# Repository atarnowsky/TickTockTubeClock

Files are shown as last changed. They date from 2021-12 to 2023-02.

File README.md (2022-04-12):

# TickTockTubeClock
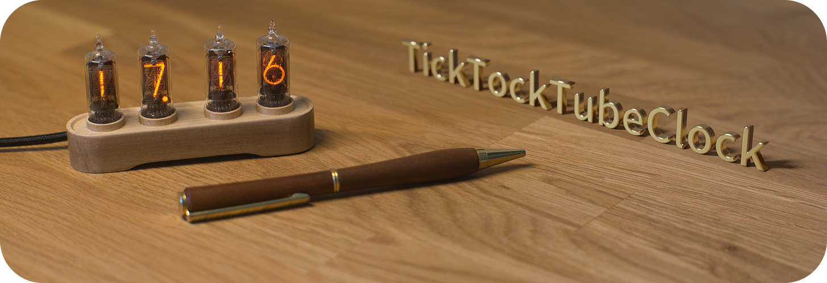
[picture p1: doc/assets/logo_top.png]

The TickTockTubeClock is an open source, open hardware Nixie-Clock with pleasing aesthetics and rich functionality in mind. It combines old nixie tubes from the late sixties with modern miniaturized electronics, 3D printing and pretty advanced wood milling.  

## Background & Introduction
Back in 2020 I gained more and more interest in CNC machining as well as electronic engineering. Searching for a project to overcome lockdown during the pandemic, I stumbled upon an old, defective electrical calculator made by Canon in the late sixties (a Monroe 630, to be more precise - similar to [this one](https://www.oldcalculatormuseum.com/monroe620.html)). Luckily, all 14 Nixie tubes were in good shape, so I decided to make some clocks out of them.

There are many different designs [out there](http://www.electricstuff.co.uk/nixiegallery.html). However, I felt most of them being a little bit too clumsy for the very small [CD81 Tubes from Hitachi](https://www.swissnixie.com/tubes/CD81/), that have been salvaged from the calculator. With the digits only being about 13 mm in height, I decided to design a housing that aesthetically complements these tiny tubes before actually thinking about how to get this thing to work electrically (not to mention to manufacture the housing). There just *had* to be a way to shrink down the electronics...

## Features
* Probably one of the smallest housings possible for a nixie tube that can be either *milled from wood* or *3D printed* using FDM or SLA printers
* Stacked two-PCB construction allows for easy adaption to other nixie tubes with same form factor
* Completely powered by a 5V USB-C connector
* Supercap based backup battery allowing to compensate power losses up to 36 hours
* Color-matched base light
* Sound output and ambient light sensor for automatic dimming
* Easy to program, extensible software interface
* Default firmware ships with:
  * Intuitive 3-button interface
  * Dimming tube and LED brightness (separately)
  * Adjustable ticking sounds
  * 4 different types of cross-fade effects (e.g. fade to black, crossfade)
  * 4 different types of ambient effects (e.g. sporadic flickering of tubes, misfiring effects)
  * Automatic night time dimming based on ambient light
  * Configurable off-time to save power and prolong tube life
  * Readout of temperature sensor of RTC
  * Anti cathode poisoning mode

## Gallery
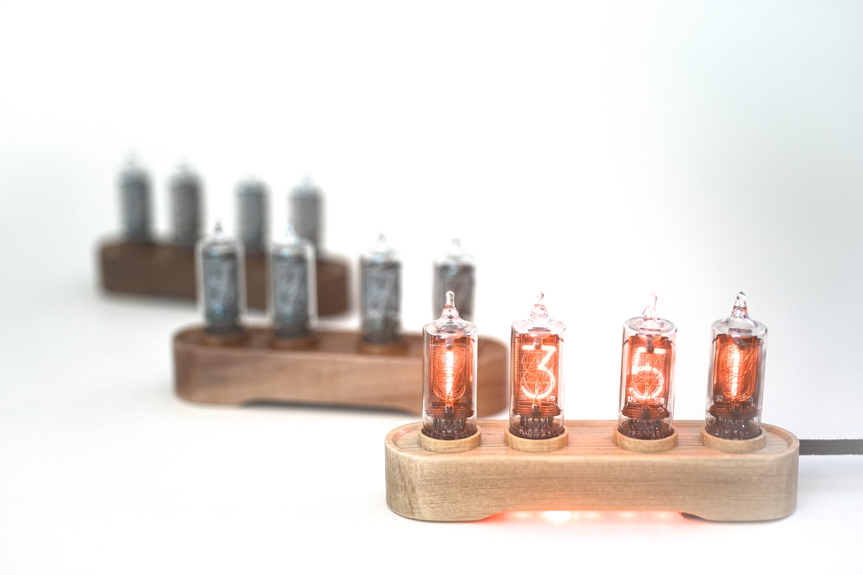
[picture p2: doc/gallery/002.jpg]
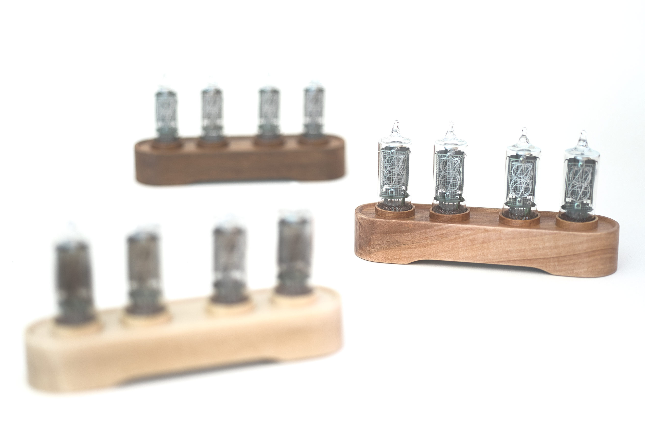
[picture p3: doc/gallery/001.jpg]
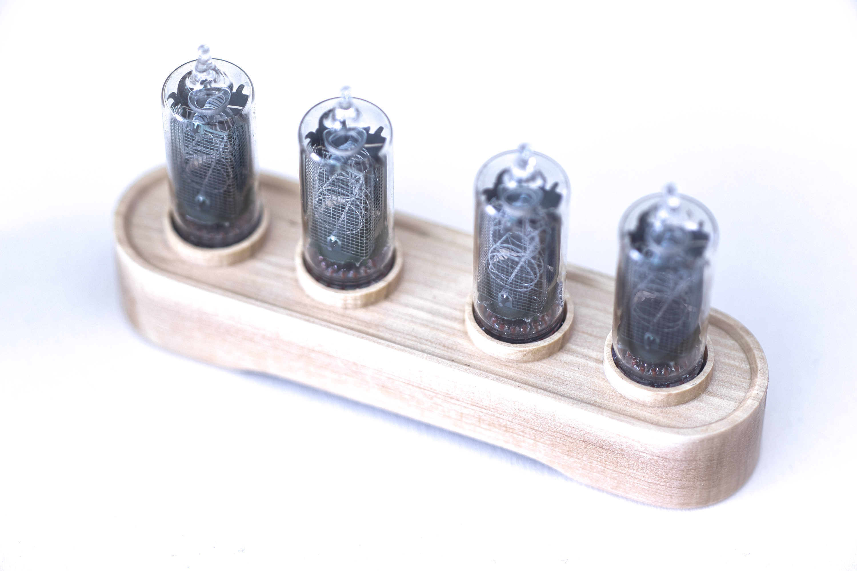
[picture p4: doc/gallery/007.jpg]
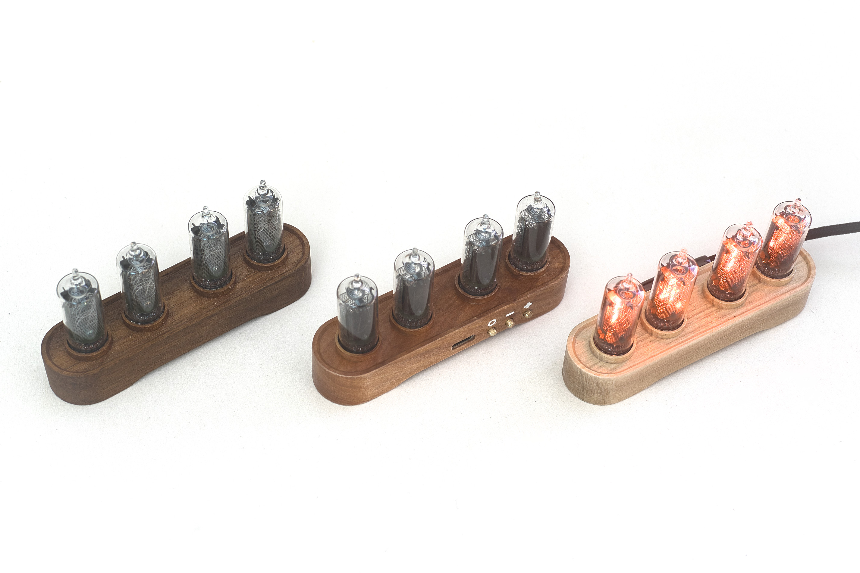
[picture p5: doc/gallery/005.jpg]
|||||
|:---:|:---:|:---:|:---:|
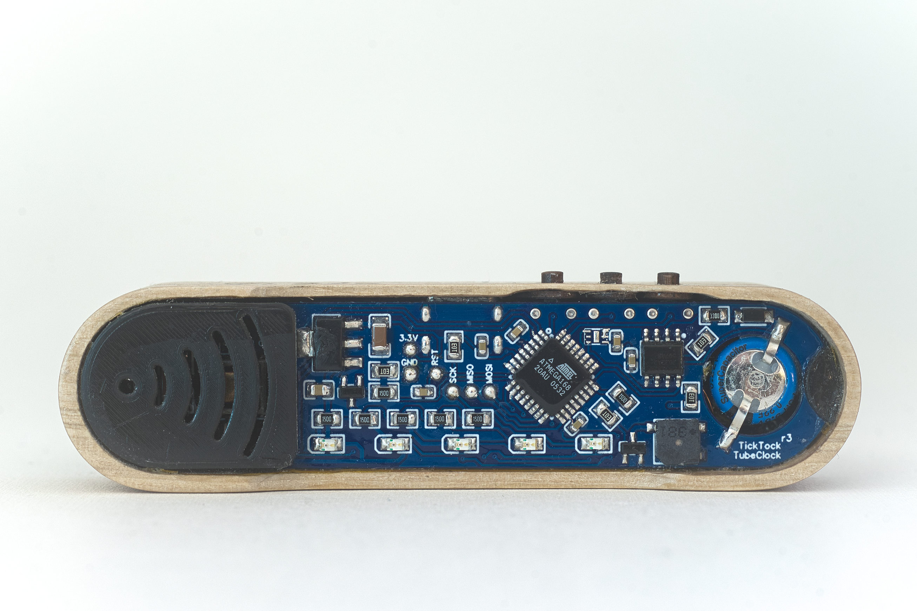
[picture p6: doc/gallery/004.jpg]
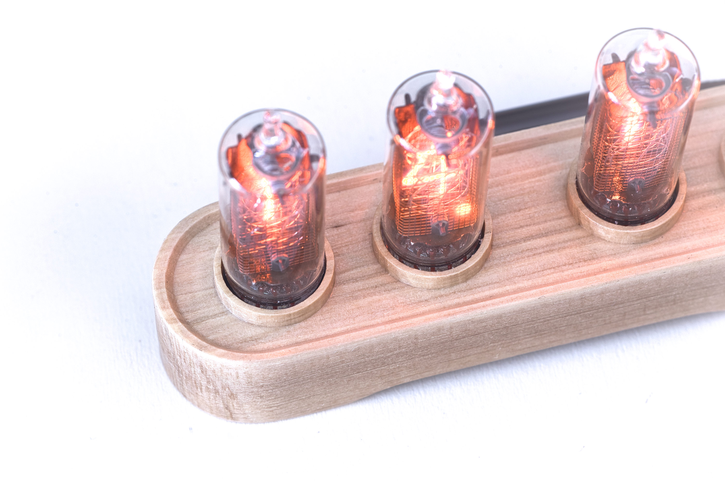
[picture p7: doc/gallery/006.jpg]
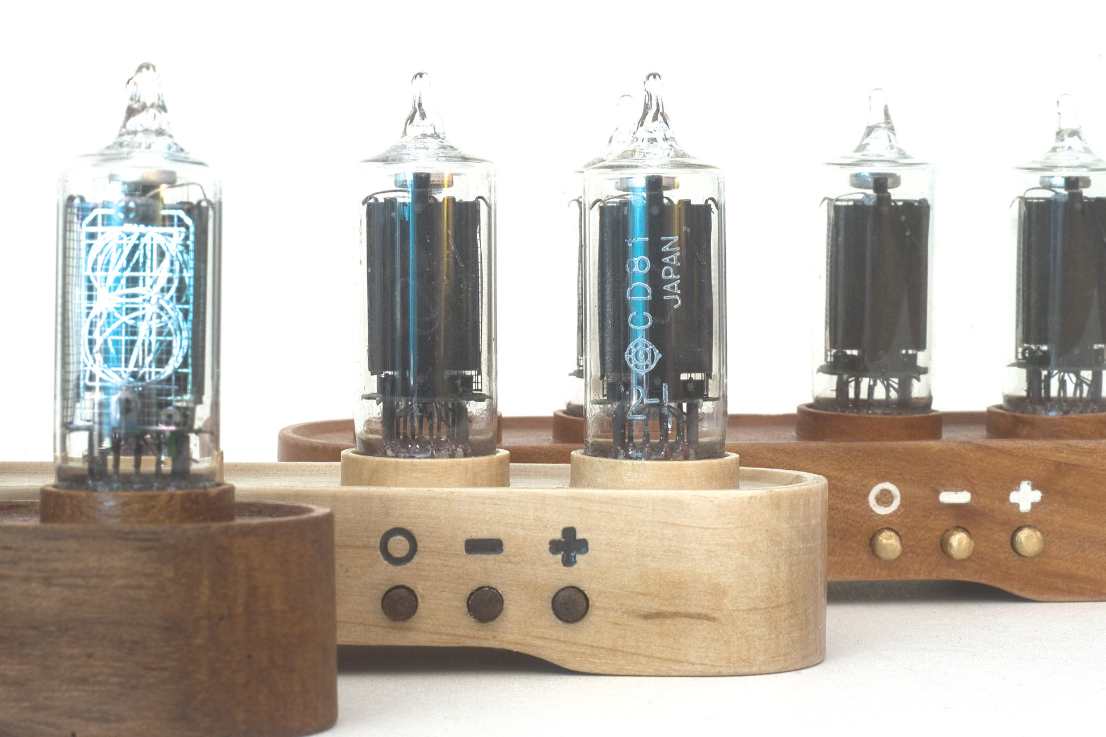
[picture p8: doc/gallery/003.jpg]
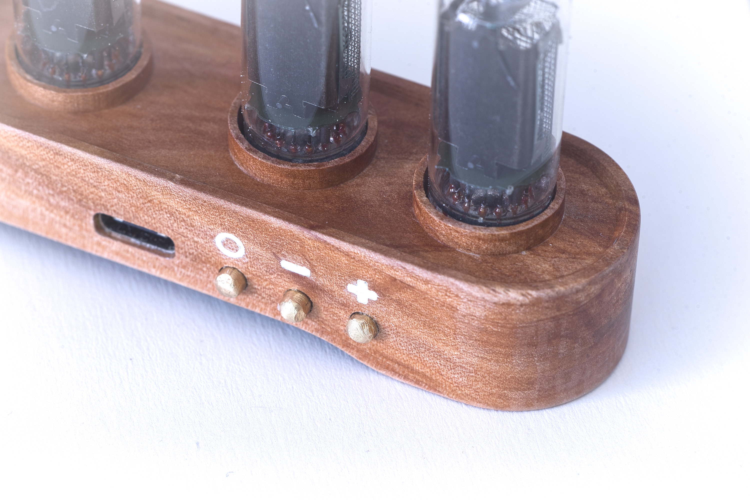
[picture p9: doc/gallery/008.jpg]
|||||

# Technical Data & General Concept
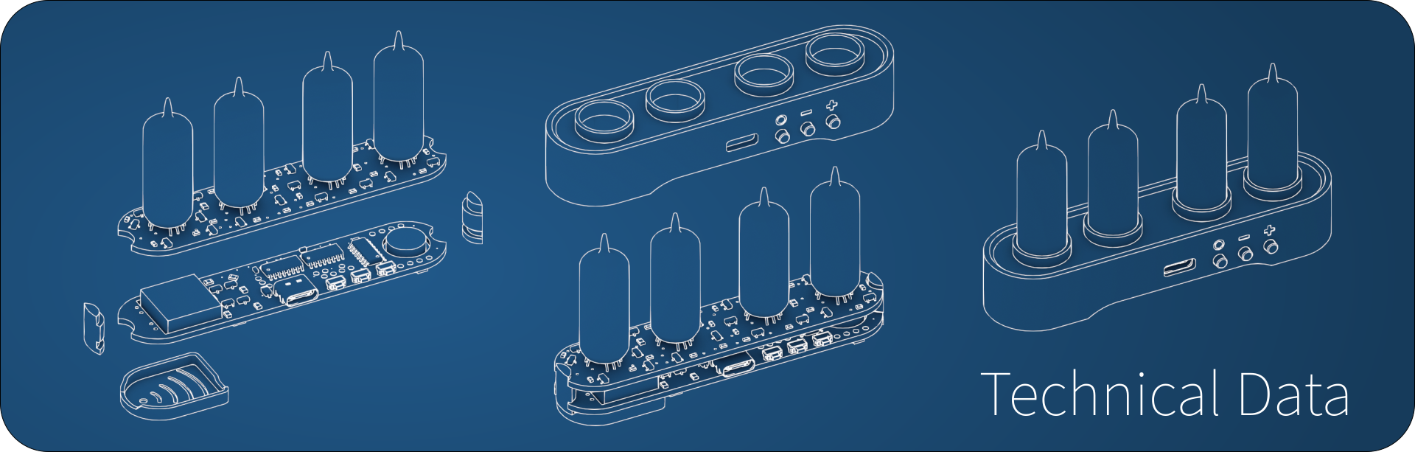
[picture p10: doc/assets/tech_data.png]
Technical Data

The clock consist of multiple parts to achieve the small form factor:
* **Upper module:** The upper PCB mounts four nixie tubes as well as the switching electronics that allows to select the digit to be visible by means of a 5V logic signal. Current limiting is done on this module, making it relatively easy to re-design this PCB for different kinds of nixie tubes without needing to change the lower module.
* **Lower module:** The lower PCB hosts the microcontroller as well as some shift registers that allow to control individual digits. It also contains two high-side switches allowing to mux between two pairs of tubes. This not only reduces the complexity of the switching electronics, but also allows to dim the tubes by using pulse width modulation. Additionally, this board includes two cutouts for mounting the DC/DC converter and a 0.2 F supercapacitor without sacrificing the overall height of the module.
* **Spacers and touch protection:** These 3D printed parts seperate upper and lower module from each other to prevent accidential contact between electrical parts. This space is also needed to route a total of 25 insulated copper wires between both PCBs, transmitting logic as well as high voltage signals. The touch protection contains several holes to allow for some ventilation and prevents accidential contact with the exposed high voltage part of the electronics.
* **Case:** The case can either be made from hardwood or by 3D printing. In either case, the machining tools need to be quite precise since the material thickness ranges from only 0.75 mm to 2.0 mm.

<br />

| Mechnical specs. | | Electrical specs. | |
| - | -: | - | -: |
| Dimensions (width × depth × height) | 9.5 × 2.45 × 5.0 cm | Supply voltage | 5V |
| Weight | approx. 35 g| maximum power consumption | 2.5 W |
| electrical components | 114 | Accuracy | ±2.6 minutes/year |

<br /><br />

# Making your own & Prerequisites

Making the TickTockTubeClock is quite a time consuming endeavor and you will need some mechanical equipment as well as good soldering skills.

## Mechanical equipment
* **3D Printer:**
Either a FDM printer with a rather fine (0.2 mm) nozzle or a SLA printer is fine. The printer is mainly needed for some internal spacers as well as a cover for the high voltage electronics.
  * Theoretically, the whole case can be 3D printed. The result, however, won't be as pleasing as a milled case.
  * When ordered in bulk, using online services such as Shapeways or JLCPCB might be a viable option. <br /><br />

* **CNC Mill:** The mill has to be quite precise but does not neet to be particularly large.
  * It is definitively possible to use a cheap 3018 style CNC mill (I actually did all parts on a slightly modified 3018!). However, you probably need to use very slow feeds, so milling the case out of hard wood will take *many* hours.
  * The 3D geometry to be milled is quite complex, so you will need a powerfull CAM tool for generating tool paths. I used Fusion 360 for CAD as well for CAM.<br /><br />

* **Milling bits:**
  * 3 to 6 mm flat end mill (two flute, for wood) with at least 22 mm cutting edge length.
  * 2 mm flat end mill (two flute, for wood) for fine details.
  * 0.5 - 1 mm end mill for USB port and button cutouts on side.
  * V carve routing bit for details on side.

## Electronics
* **Components:** Please have a look at the Bill of Materials. (As soon as I uploaded it...)
* **DC/DC converter**: This is a tricky one, since we need a DC/DC converter with a large voltage ratio (5V -> 170V). I finally found a suitably small one on Aliexpress: [DKYB DC 5V-9V to 170V](https://www.aliexpress.com/item/32990383358.html).
* **Additional isolation:** To be on the save side when handling a device with high voltages, I heavily recommend to apply some conformal coating on the assembled PCB. I used a [acrylic based one](https://cramolin-shop.de/cramolin-plastik-400-ml-spraydose-1201611) with great results.
* **SMD soldering:** All components can be soldered by hand (mostly 0805, some 0603 footprints). There are, however, some delicate parts in the BoM that need a steady hand and good eyes (or a microscope). Especially the USON6 package of the [OPT3001](https://www.ti.com/lit/ds/symlink/opt3001.pdf?ts=1649591341957&ref_url=https%253A%252F%252Fwww.google.com%252F) ambient light sensor is quite challenging.

## Software
* The clock uses an ATMega 168 processor from microchip. The programming/flashing is done via PlatformIO.
* There just was not enough space for a USB to serial chip on the PCB, so a ISP programmer is needed for flashing the device.

<br />

**More information and some tutorials are coming soon...**

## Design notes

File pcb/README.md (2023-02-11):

# Bill of Materials

There was simply not enough space on the PCB for proper designators. Instead, please consult the color-code besides the _No._ column and the respective images of the PCB.

Number column: 

**A** = Lower PCB / Lower side, **B** = Lower PCB / Upper side

**C** = Upper PCB / Lower side, **D** = Upper PCB / Upper side

### Integrated Circuits, Diodes & Mosfets
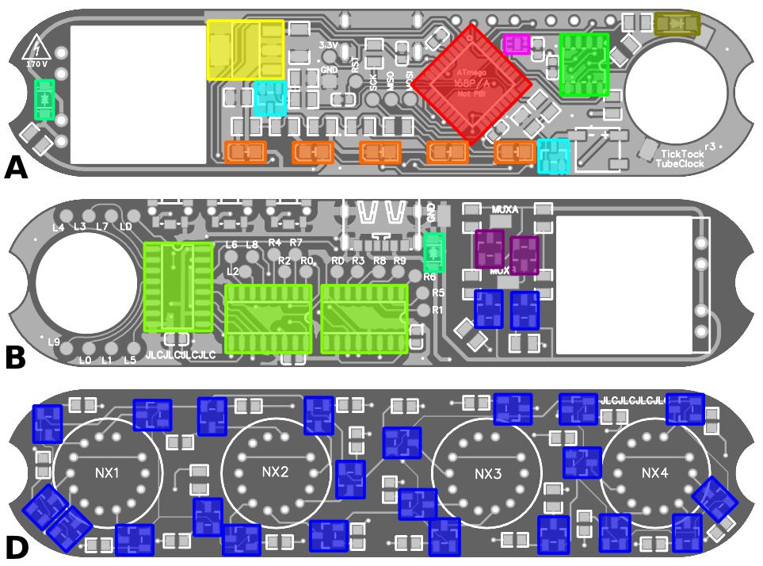
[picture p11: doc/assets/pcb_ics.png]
Components: ICs


| No. | Qty | Package | Manufacturer | Part number | Description | Alternatives |
|---|-----|---|---|---|---|---|
| #ff0000 A1 | 1 | QFP32 | Microchip | ATMEGA168-20AU | 8bit microcontroller | P variant is also okay, but **not -PB!**. ATMEGA328 if more memory is needed. |
| #ffff00 A2 | 1 | SOT-223 | Texas Instruments | LM3940IMP-3.3  | Voltage regulator 3.3V | Any pin-compatible LDO proably will do. However, stabilizing capacitors need adjusment depending on data-sheet. |
| #00ff00 A3 | 1 | SOIC-8  | Maxim Integrated  | DS3232MZ/V+ | Real time clock with integrated oscillator | DS3231MZ+, DS3231M (both untested) needs compatible footprint + internal oscillator | 
| #ff00ff A4 | 1 | USON-6  | Texas Instruments | OPT3001DNPR | Ambient light sensor | OPT3002 should work as well |
| #00ffff A5 | 2 | SOT-23  | Diodes Inc. | DMN2041L-7 | n-channel MOSFET | IRLML2502 or similar, needs a 3.3V logic level compatible Gathe-threshold voltage (< 1.5V) |
| #ff6600 A6 | 5 | 0805 | Würth Elektronik  | 150080AS75000  | LED Amber/Orange 2V/20mA | Any similar LED will do. Using a color matching the nixies closely recommended. |
| #808000 A7 | 1 | SOD-123 | Nexperia | BAT54GWX | Schottky diode | Maybe RB168MM-40. **See description below** |
| #00ff80 AB8  | 2 | SOD-123 | Eaton | STS321050B331  | TVS diode | Used for securing the USB port as well as the 5V input rail of the DC/DC convertor (in case of voltage spikes when malfunctioning). |
| #80ff00 B9 | 3 | SOIC-16 | Texas Instruments | SN74HC595 | 8bit shift register | |
| #800080 B10  | 2 | SOT-23  | Various | MMBTA92 | High voltage transistor, p-channel | |
| #0000ff BC11 | 24  | SOT-23  | Various | MMBTA42 | High voltage transistor, n-channel | |

**Note on schottky diode (A7)**

This diode is used for charging the supercapacitor and needs special attention in order to maximize battery backup time:
Ideally, a diode is chosen with an extremely low forward voltage (so the maximum charging voltage of the supercap is near 3.3V) as well as a very low reverse current (preventing discharge over time).
After some quite extensive search, the BAT54GWX seems to be a reasonable choice. For a maximum voltage of 3.3V, the reverse current should be as low as 0.5 µA while the voltage drop should stay below 240 mV.
The current consumption of the RTC in backup mode typically is about 1.8 µA, so further reducing the reverse current of the diode should significantly prolong battery backup time.

Using the BAT54GWX, about 30-36 hours of backup time can be expected. <br />
**If you find a better diode, please tell me!**

### Capacitors & Resistors

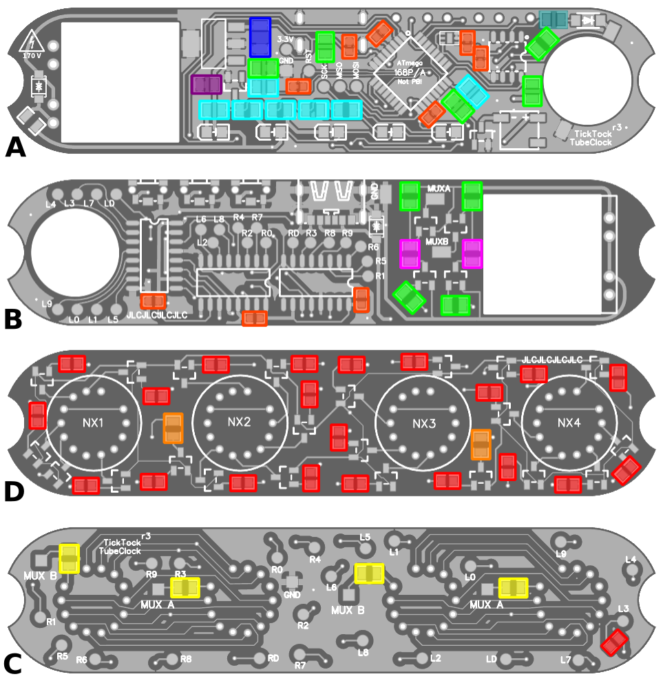
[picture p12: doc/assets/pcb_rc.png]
Components: Resistors and Capacitors


| No. | Qty | Package | Description | Annotations |
|---|-----|---|---|---|
| #ff4000 AB12  |  9  | 0603 | **C:** 100nF/50V X7R Generic decoupling capacitor | 16V rating should be also sufficient. |
| #800080 A13 |  1  | 0805 | **C:** 470nF/25V X7R capacitor | Needs to be matched with LDO specifications. |
| #0000FF A14 |  1  | 1206 | **C:** 33µF/16V X5R capacitor | Needs to be matched with LDO specifications. |
| #00FF00 AB15  |  9  | 0805 | **R:** 10kΩ resistor 1/4W | Can be replaced with something in the 4-16kΩ range. |
| #00FFFF A16 |  7  | 0805 | **R:** 150Ω resistor 1/4W | |
| #008080 A17 |  1  | 0805 | **R:** 150Ω resistor 1/4W | For charging the supercap. Reduce value for faster charging, but shorter supercap life. |
| #FF00FF B18 |  2  | 0805 | **R:** 1MΩ resistor 1/8W | Mega-Ohms! You really do not want milli Ohms here ;-) |
| #FF8000 D19 |  2  | 0805 | **R:** 2.4kΩ resistor 2/5W | Controls relative brightness of decimal-dots. Might be varied to match better. |
| #FF0000 BC20  | 22  | 0603 | **R:** 10kΩ resistor 1/4W | |
| #FFFF00 C21 |  4  | 0805 | **R:** 16kΩ resistor 2/5W | In theory, these should be ~2W rated. However, due to multiplexing and PWM effective current is greatly reduced. |

### Other Components

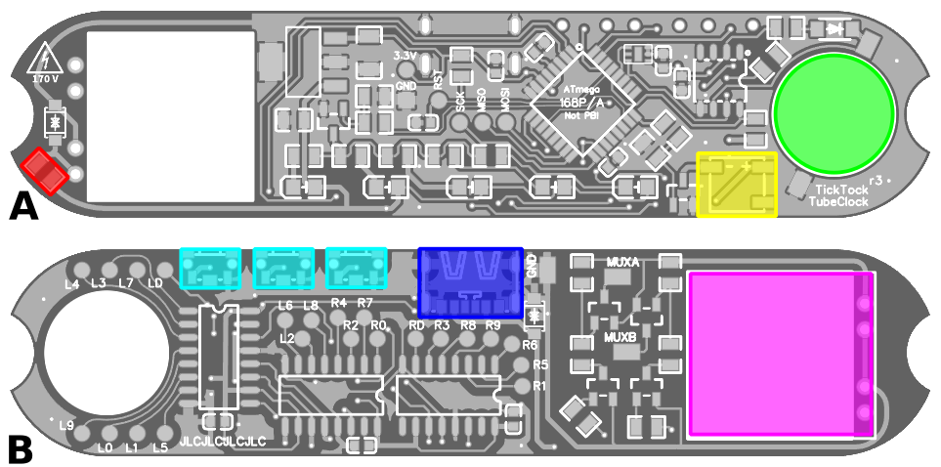
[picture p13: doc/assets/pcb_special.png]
Components: Special


| No. | Qty | Package | Manufacturer | Part number | Description | Alternatives |
|---|-----|---|---|---|---|---|
| #ff0000 A22  | 1 | 0603 | Bourns | SF-0603HI075F-2 | Fuse 750mA High Inrush Withstand | 500mA might be sufficient as well. Needs long-time testing. 0Ω jumper if you feel adventurous. |
| #ffff00 A23  | 1 | special | CUI Devices | CMT-5023S-SMT-TR | Magnetic Buzzer | KELIKING KLJ-5018 is cheaper but sounds worse. |
| #00ff00 A24  | 1 | special | Various | | Super Capacitor >3.3V | **See description below** |
| #00ffff B25  | 3 | special | Diptronics | TCD-C2KQR | Right angle tactile switch | |
| #0000ff B26  | 1 | special | Korean Hroparts Elec | TYPE-C-31-M-16 | USB-C Power-only jack | |
| #ff00ff B26  | 1 | THT | DKYB | [Link](https://www.aliexpress.com/item/32990383358.html) | 5V to 170V DC/DC converter | If you are able to design a on-board circuit, please contact me! |

**Note on supercapacitor (A24)**

Any supercapacitor with (at least) 3.3V will be fine. Use a higher voltage one and/or larger values for A17 to prolong its life expectancy.
The PCB originally has been designed to hold a *5V/0.1F Eaton Gold Cap* (10mm diameter, 4mm height), but slightly larger ones should also fit (max. diameter 12mm, max. height about 6mm).
With 0.1F capacity, one can expect about 30h of timekeeping if USB power is lost.
Choosing a hibrid capacitor, like the Vishay MAL219691203E3 (should barely fit), with 15F/4.2V a total of 60 days should be possible. However, I am unsure regarding the life expectancy of the cell and its self discharging properties.

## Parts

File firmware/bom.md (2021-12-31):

# Bill of materials

All costs are approximate (in €) basedon Digikey prices as of 2022. (Including bulk discount, values are for reference only.)

## Upper PCB

| Comment | Description | Designator | Footprint | Amount | Price (sum.) | Link | Remarks |
| --- | --- | --- | --- | --- | --- | ---- | --- |
| Old stock | Hitachi CD81 | NX1, NX2, NX3, NX4 | Custom | 4 |  n/a | n/a | Might be salvaged from old Canon calculators. (Do not get fooled by Ebay prices!) |
| ESR10EZPJ163 | 16k Resistor, 0.4 W | R1, R32, R57, R58 | 0805 | 4 | 0.12 € | [Digikey](https://www.digikey.de/de/products/detail/rohm-semiconductor/ESR10EZPJ163/4051315) | Be careful wrt. voltage ratings. |
| RCS08052K49FKEA | 2.4k Resistor, 0.4 W | R55, R56 | 0805 | 2 | 0.39 € | [Digikey](https://www.digikey.de/de/products/detail/vishay-dale/RCS08052K49FKEA/5869310) | Be careful wrt. voltage ratings. |
| ESR03EZPJ103 | 10k Resistor, 0.125 W | R33-R54 | 0603 | 22 | 0.62 € | [Digikey](https://www.digikey.de/de/products/detail/rohm-semiconductor/ESR03EZPJ103/1762722) |  |
| MMBTA42,215 | NPN HV-Transistor | Q1-Q11, Q16-Q26 | SOT-23-3 | 22 | 2.18 € | [Digikey](https://www.digikey.de/de/products/detail/nexperia-usa-inc/MMBTA42-215/1156601) | |

## Lower PCB

| Comment | Description | Designator | Footprint | Amount | Price (sum.) | Link | Remarks |
| --- | --- | --- | --- | --- | --- | ---- | --- |
| CMT-5023S-SMT-TR | Buzzer 5x5mm | BUZZER | Custom | 1 |  2.55 € | [Digikey](https://www.digikey.de/de/products/detail/cui-devices/CMT-5023S-SMT-TR/6012414) | Cheaper alternative from [LCSC](https://lcsc.com/product-detail/Buzzers_KELIKING-KLJ-5018_C201045.html) |
| OPT3001DNPR | Ambient light sensor | U3 | 6-UDFN | 1 | 2,77 € | [Digikey](https://www.digikey.de/de/products/detail/texas-instruments/OPT3001DNPR/5039362) | Hard to solder by hand | 
| SMMBTA92LT1G | PNP HV-Transistor | Q12, Q14 | SOT-23-3 | 2 | 0.58 € | [Digikey](https://www.digikey.de/de/products/detail/onsemi/SMMBTA92LT1G/3062778) ||
| MMBTA42,215 | NPN HV-Transistor | Q13, Q28 | SOT-23-3 | 2 | 0.20 € | [Digikey](https://www.digikey.de/de/products/detail/nexperia-usa-inc/MMBTA42-215/1156601) | |
| MFU0805FF00500P100 | Fuse 500mA | F1 | 0805 | 1 | 0,49 € | [Digikey](https://www.digikey.de/de/products/detail/vishay-beyschlag-draloric-bc-components/MFU0805FF00500P100/1206486) | |
| STS321050B331 | TVS Diode 5.5V | ? | SOD-323 | 1 | 0.25 € | [Digikey](https://www.digikey.de/de/products/detail/eaton-electronics-division/STS321050B331/13280450) ||
| SN74HC595DR | Shift register 8bit | U7, U8, U9 | SOIC-16 | 3 | 1.34 € | [Digikey](https://www.digikey.de/de/products/detail/texas-instruments/SN74HC595DR/562919) ||
| LM3940IMPX-3.3/NOPB | 3.3V Linear regulator | U4 | SOT-223-4 | 1 | 1.46 € | [Digikey](https://www.digikey.de/de/products/detail/texas-instruments/LM3940IMPX-3-3-NOPB/367097) ||
| C3216X5R1C336M160AB | Capacitor 33µF | C3 | 1206 | 1 | 0.70 € | [Digikey](https://www.digikey.de/de/products/detail/tdk-corporation/C3216X5R1C336M160AB/2443480) || 
| CL21B474KAFNNNE | Capacitor 470nF | C4 | 0805 | 1 | 0.03 € | [Digikey](https://www.digikey.de/de/products/detail/samsung-electro-mechanics/CL21B474KAFNNNE/3886732) ||
| CL10B104KB8WPNC | Capacitor 100nF | C2, C5-C10 | 0603 | 7 | 0.13 € | [Digikey](https://www.digikey.de/de/products/detail/samsung-electro-mechanics/CL10B104KB8WPNC/5961338) ||
| ERJ-P06J151V | Resistor 150 | R2, R9-R14, R24 | 0805 | 8 | 0.29 € | [Digikey](https://www.digikey.de/de/products/detail/panasonic-electronic-components/ERJ-P06J151V/525217) ||
| RMCF0805JG10K0 | 10k Resistor, 0.125 W | R3, R5, R8, R25, R26, R28, R29 | 0805 | 7 | 0.09 € | [Digikey](https://www.digikey.de/de/products/detail/stackpole-electronics-inc/RMCF0805JG10K0/1757769) |  | 
| RMCF0805JT1M00 | 1M Resistor, 0.125 W | R27, R30 | 0805 | 2 | 0.02 € | [Digikey](https://www.digikey.de/de/products/detail/stackpole-electronics-inc/RMCF0805JT1M00/1757878) || 
| UJC-HP-3-SMT-TR | USB-C Terminal | USB1 | | 1 | 0.88 € | [Digikey](https://www.digikey.de/de/products/detail/cui-devices/UJC-HP-3-SMT-TR/12173295) || 
| DS3232MZ+TRL | RTC integrated Osc. | U2 | SOIC-8 | 1 | 7,91 € | [Digikey](https://www.digikey.de/de/products/detail/analog-devices-inc-maxim-integrated/DS3232MZ-TRL/3087654) || 
| RB168MM-30TR | Diode (Schottky) | D1 | SOD-123 | 1 | 0.31 € | [Digikey](https://www.digikey.de/de/products/detail/rohm-semiconductor/RB168MM-30TR/10670912) | Use low drop out AND very low leakage current diode (standard or schottky) to prolong buffer time | 
| DMN2041L-7 | MOSFET | Q15, Q27 | SOT-23-3 | 2 | 0.36 € | [Digikey](https://www.digikey.de/de/products/detail/diodes-incorporated/DMN2041L-7/2182568) | Use any FET with low Vgs(th), 3.3V compatible |

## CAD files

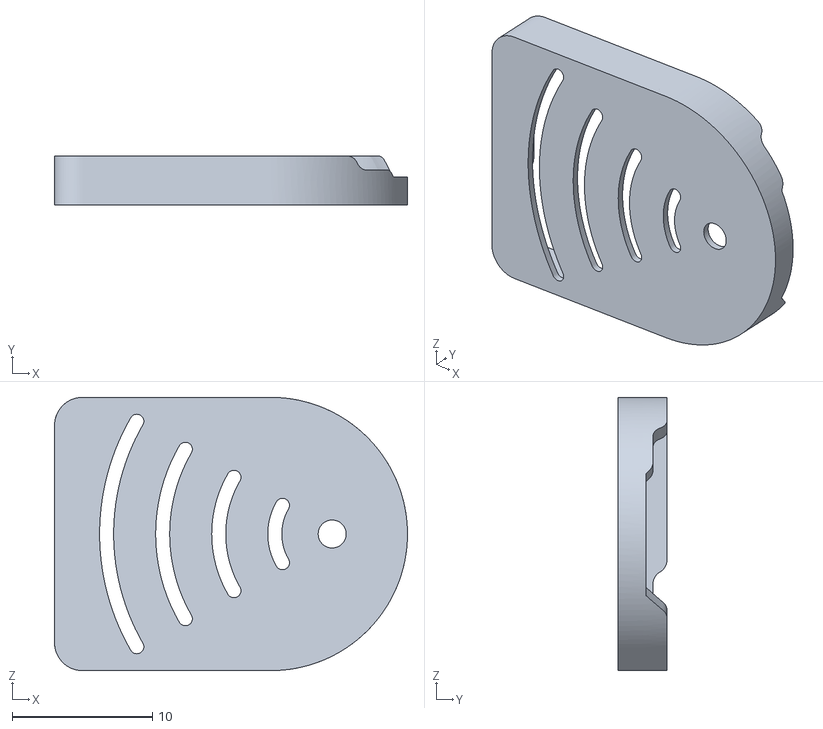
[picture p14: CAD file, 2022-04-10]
cad/stl/touch_guard.stl
25.2 x 3.50 x 19.5

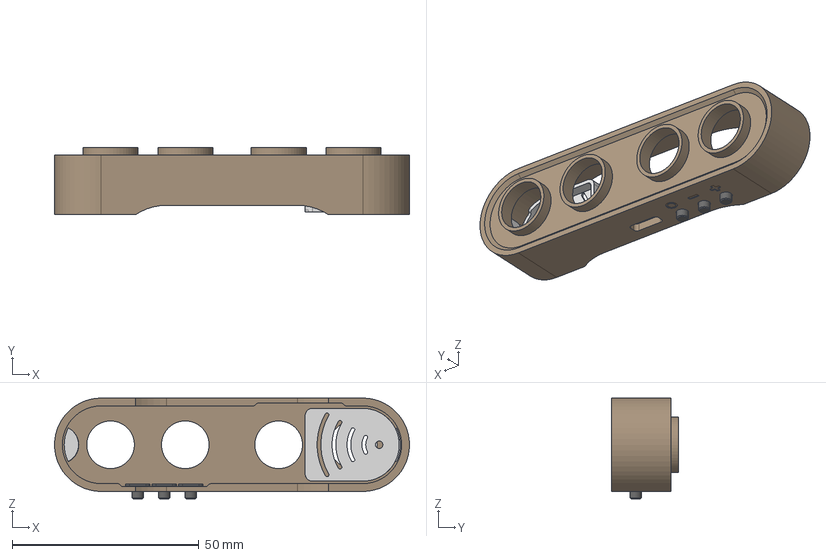
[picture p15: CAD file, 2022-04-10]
cad/tttc.step
95.0 x 18.0 x 27.0 mm
Case
SLA Printed inner spacer

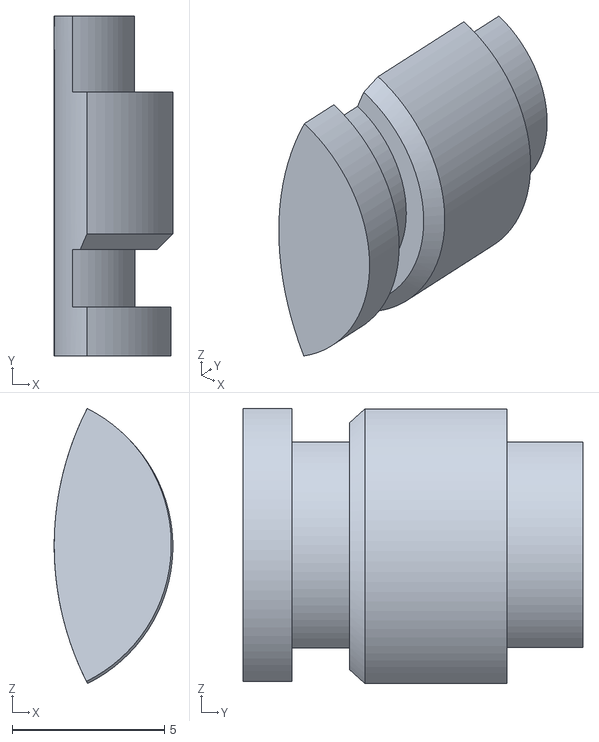
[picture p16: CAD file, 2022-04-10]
cad/stl/spacer.stl
3.89 x 11.1 x 9.03

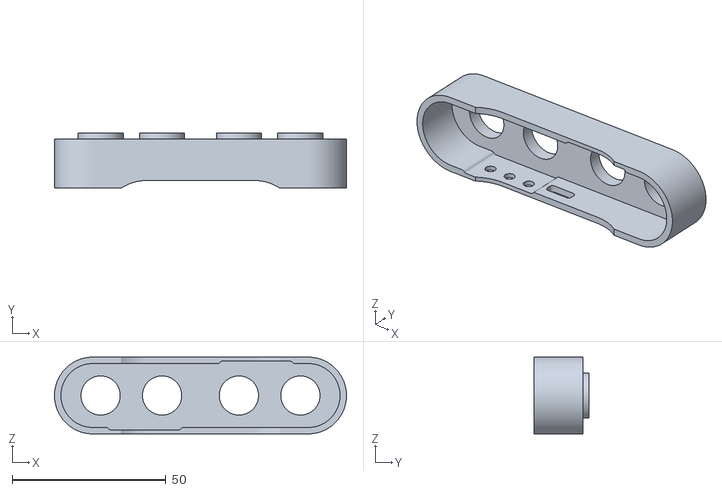
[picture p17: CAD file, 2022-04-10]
cad/stl/case.stl
95.0 x 18.0 x 25.0

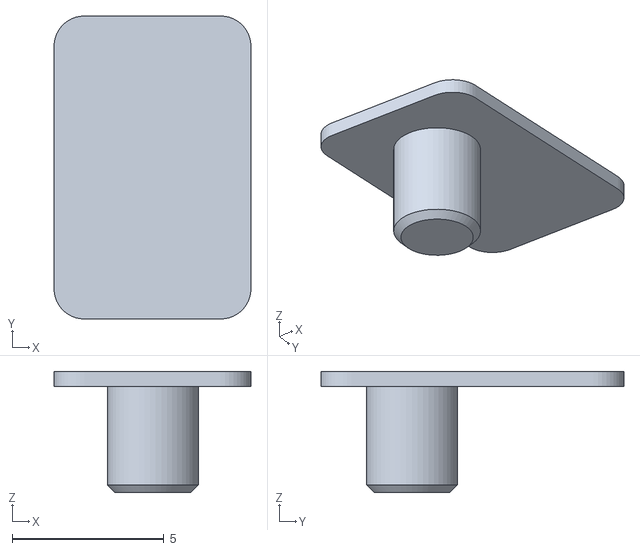
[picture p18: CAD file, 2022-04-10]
cad/stl/button_single.stl
6.50 x 10.0 x 4.00

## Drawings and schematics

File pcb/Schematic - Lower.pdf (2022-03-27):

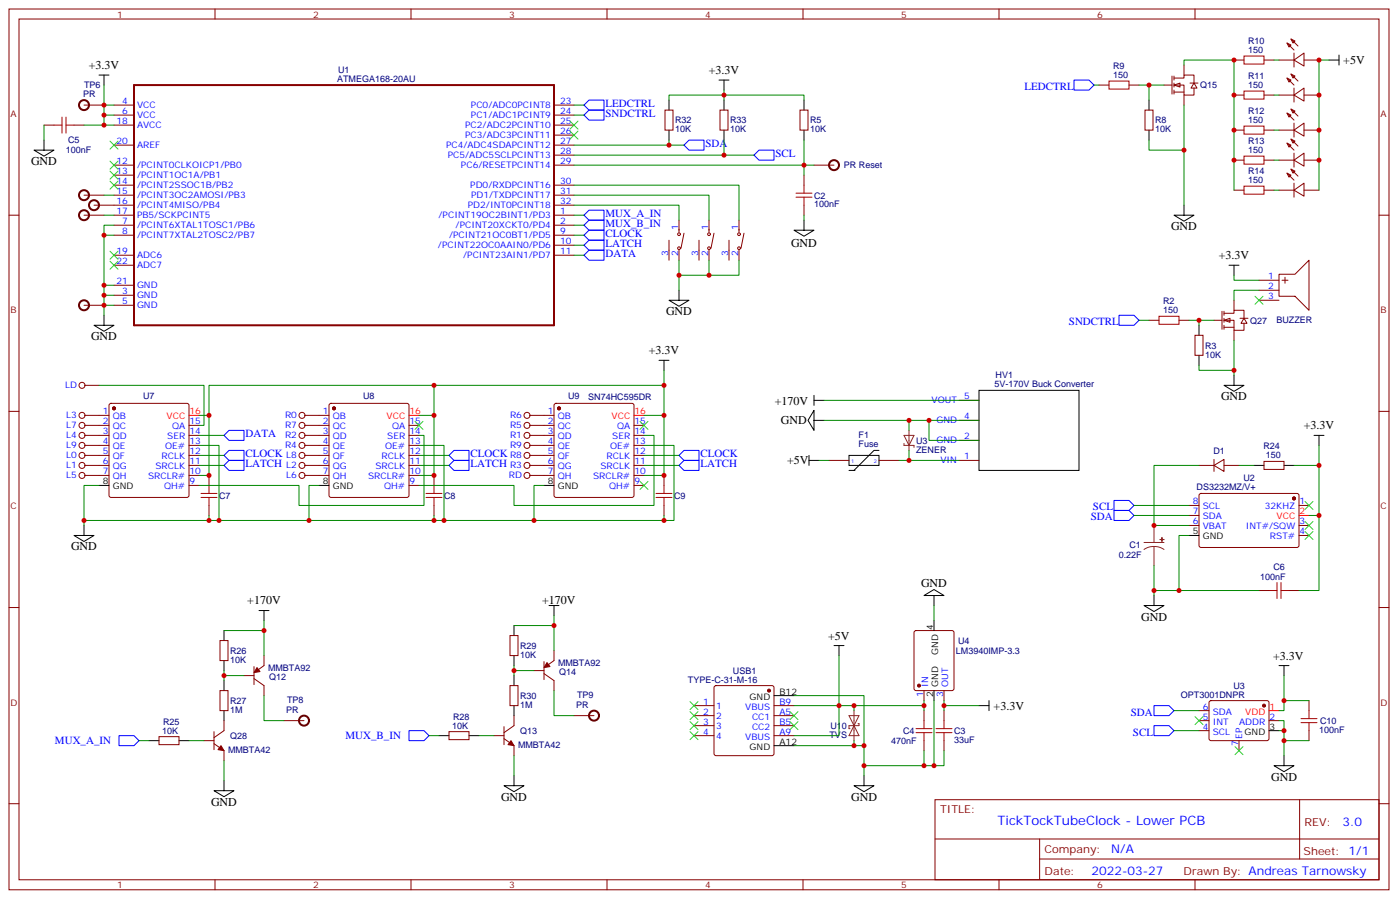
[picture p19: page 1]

SRCLR# 10 SRCLK 11 RCLK 12 OE# 13 SER 14 QA 15 VCC 16

Drawn By: Andreas Tarnowsky

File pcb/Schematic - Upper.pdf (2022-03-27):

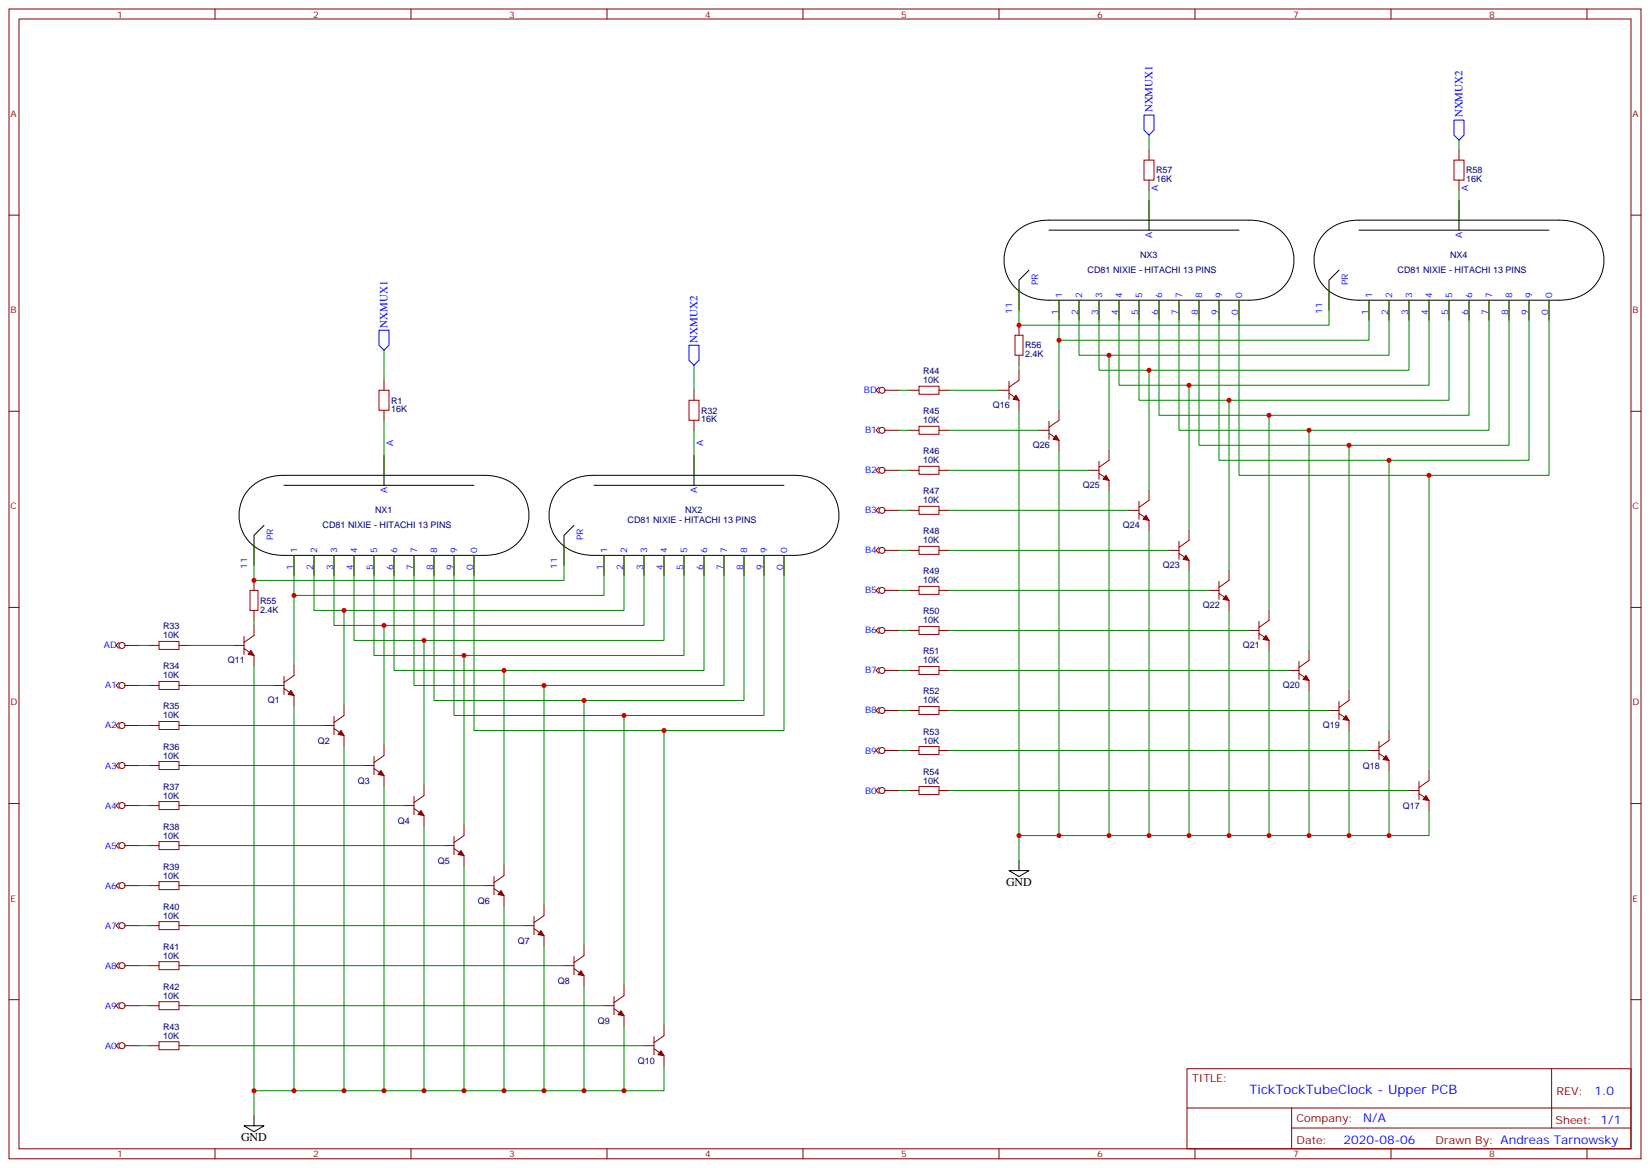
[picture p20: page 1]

Drawn By: Andreas Tarnowsky

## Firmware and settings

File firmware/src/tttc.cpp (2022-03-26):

//#define BENCHMARK
#include <Arduino.h>

#include "io_tools.h"
#include "hw_map.h"

#include "sound.h"
#include "display.h"
#include "ambient_light.h"
#include "timing.h"
#include "base_light.h"

#include "state.h"
#include "state_machine.h"  
#include "scheduler.h"
#include "effects.h"
#include "settings.h"
#include "safety.h"

#include "simple_i2c.h"

#include "state_clock.h"
#include "state_timeset.h"
#include "state_settings.h"
#include "state_service.h"

#include "configuration.h"


using sched = Scheduler<3840, 
  Display::ShiftPWMProcessor, // @3840 Hz critical clock and 5 bit pwm: 120 Hz update rate
  Display::AntiCathodePoisoning,
  Effects::Transition,
  Effects::Ambient,
  Safety::TemperatureCheck,
  BaseLightDimmer,    
  RTCSync,
  //AmbientLight,
  UI
  //TimingBenchmark  
>;

void setup() {    
  Pins::setup();  
  I2C::initialize();
  
  BaseLightDimmer::set_fade_speed(2);
  BaseLightDimmer::set_brightness(0);

  sched::initialize();
  

  if(Settings::on_first_start()) {
    pause_critical();
    SoundGenerator::play(Note{659, 100, 75*3});
    SoundGenerator::play(Note{523, 100, 75});
    SoundGenerator::play(Note{659, 100, 125});
    SoundGenerator::play(Note{880, 200, 75});
    delay(250);
    resume_critical();
  }  


  sched::start_critical();
  sched::start_relaxed();
}

void loop() {
  // Will never be called
  // TODO: use traditional main() function instead of this Arduino stuff...
}

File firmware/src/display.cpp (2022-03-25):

#include "display.h"
#include "hw_map.h"

namespace Display {

    // There are a total of four buffer used, two for showing numbers (MUXA and MUXB)
    // the other two for dots only. Both are shown in alternating order.
    // This effectively cuts the maximum brightness in half, but
    // the blank frame between numbers reduces ghosting a lot!
    // Additionally, putting the dots into the same buffer as the numbers go
    // would result into a slight but noticable change in the according
    // numbers brightness due to the common anode.
    // Displaying numbers and dots in alternating order assures both get the
    // same amount of current.
    constexpr uint8_t register_count = 3;
    static volatile uint8_t register_buffers[4][register_count] = 
    {
        //     BANK0       BANK1       BANK2
        { 0b00000000, 0b00000000, 0b00000000}, // Ones
        { 0b00000000, 0b00000000, 0b00000000}, // Blank / Ones Dot
        { 0b00000000, 0b00000000, 0b00000000}, // Tens
        { 0b00000000, 0b00000000, 0b00000000}  // Tens Blank / Tens Dot
    };

    volatile ShiftPWMProcessor::MUXMask mux_mask = ShiftPWMProcessor::MUXMask::BOTH;


    namespace {
        uint16_t fade_state = 0;
        uint16_t fade_target = 0;
        uint8_t fade_increment = 0;
    }

    // ShiftPWMProcessor ---
    void ShiftPWMProcessor::initialize(uint16_t update_rate) {
        clear(); // Clear registers to assure no random numbers show up on startup
    } 

    volatile uint8_t& ShiftPWMProcessor::alter_buffer(uint8_t bank, uint8_t number) {
        return register_buffers[number][bank];
    }

    void ShiftPWMProcessor::alter_buffer(const uint8_t (&new_buffer)[4][3]) {
        for(uint8_t i = 0; i < register_count; i++)
                for(uint8_t j = 0; j < 4; j++)
                    register_buffers[j][i] = new_buffer[j][i];
    }

    void ShiftPWMProcessor::get_buffer(uint8_t (&copy)[4][3]) {
        for(uint8_t i = 0; i < register_count; i++)
                for(uint8_t j = 0; j < 4; j++)
                    copy[j][i] = register_buffers[j][i];
    }

    void ShiftPWMProcessor::process(uint8_t cycle_count) {  
        if(mux_mask == MUXMask::ONES) {
            show_ones(0);
            return;
        }

        if(mux_mask == MUXMask::TENS) {
            show_tens(0);
            return;
        }
        
        // Ghosting prevention: Put in a short blank frame between mux change 
        if(cycle_count % 8 == 0 || mux_mask == MUXMask::NONE) {
            show_nothing();
            return;
        }

        // Fade complete display
        if(fade_state != fade_target) {
            if(fade_state < fade_target)
                fade_state += fade_increment;
            else if(fade_state > fade_target)
                fade_state -= fade_increment;
        }

        //                                  16bit    ->       8bit        -> 0..31
        const uint8_t pwm_width = uint8_t(fade_state >> slowmotion_factor >> 3);    

        if(cycle_count % 8 > pwm_width) {
            show_nothing();
            return;
        }

        if(cycle_count < 8) 
            show_ones(0);
        else if (cycle_count < 16)
            show_ones(1);
        else if(cycle_count < 24)
            show_tens(2);
        else 
            show_tens(3);            
    }

    // Mainly used for AntiCathodePoisoning function, allowing
    // to temporarily disable muxing
    void ShiftPWMProcessor::configure_mux(MUXMask mask){
        mux_mask = mask;
    }
    
    void ShiftPWMProcessor::set_brightness(uint8_t target) {
        fade_target = target << slowmotion_factor;
        fade_state = target << slowmotion_factor;
    }

    void ShiftPWMProcessor::set_fade_target(uint8_t target) {
        fade_target = target << slowmotion_factor;
    }

    void ShiftPWMProcessor::set_fade_speed(uint8_t speed) {
        fade_increment = speed;
    }
    
    void ShiftPWMProcessor::clear() {
        // Reset registers
        for(uint8_t i = 0; i < register_count; i++)
            for(uint8_t j = 0; j < 4; j++)
                register_buffers[j][i] = 0b00000000;
        
        show_nothing();
    }
    
    void ShiftPWMProcessor::show_ones(uint8_t index)
    {
        IO::low(Pins::Shift::Latch);   
        Pins::Shift::shift_out(register_buffers[index][0], 
                               register_buffers[index][1], 
                               register_buffers[index][2]);
        IO::low(Pins::Anode::MuxA);
        IO::high(Pins::Anode::MuxB, Pins::Shift::Latch); 
    }

    void ShiftPWMProcessor::show_tens(uint8_t index) 
    {
        IO::low(Pins::Shift::Latch);   
        Pins::Shift::shift_out(register_buffers[index][0], 
                               register_buffers[index][1], 
                               register_buffers[index][2]);
        IO::low(Pins::Anode::MuxB);    
        IO::high(Pins::Anode::MuxA, Pins::Shift::Latch); 
    }                 

    void ShiftPWMProcessor::show_nothing() 
    {
        IO::low(Pins::Shift::Latch);   
        Pins::Shift::shift_out(0, 0, 0);
        IO::low(Pins::Anode::MuxA, Pins::Anode::MuxB);
        IO::high(Pins::Shift::Latch); 
    }    

    // BufferControl ---

    void BufferControl::show_time(uint16_t value){
        auto number = [](uint16_t n) -> array<uint8_t, 4> 
        {
            if(n > 9999) return {255, 255, 255, 255};
            array<uint8_t, 4>  result;
            result[3] = (n / 1000) % 10;
            result[2] = (n / 100) % 10;
            result[1] = (n / 10) % 10;
            result[0] = n % 10;
            return result;
        };

        set_numbers(number(value));  
    }

    void BufferControl::show_number(uint16_t value) {
        auto number = [](uint16_t n) -> array<uint8_t, 4> 
        {
            if(n > 9999) return {255, 255, 255, 255};
            array<uint8_t, 4>  result;
            result[3] = (n / 1000) % 10;
            result[2] = (n / 100) % 10;
            result[1] = (n / 10) % 10;
            result[0] = n % 10;
            return result;
        };

        set_numbers(number(value));  
        set_dots({false, false, false, false});  
    }

    // void BufferControl::show_number(float value) {
    //     auto number = [](uint16_t n) -> array<uint8_t, 4> 
    //     {
    //         if(n > 9999) return {255, 255, 255, 255};
    //         array<uint8_t, 4>  result;
    //         result[3] = (n / 1000) % 10;
    //         result[2] = (n / 100) % 10;
    //         result[1] = (n / 10) % 10;
    //         result[0] = n % 10;
    //         return result;
    //     };
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

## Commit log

2021-09-26 Added first revision of schematic and gerber files as well as EasyEDA jsons.
    [Gerber_BoardOutline.GKO, Gerber_BottomLayer.GBL, Gerber_BottomPasteMaskLayer.GBP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]
2021-09-26 More consistent naming.
    [Gerber_BoardOutline.GKO, Gerber_BottomLayer.GBL, Gerber_BottomPasteMaskLayer.GBP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]
2021-10-01 Centralize pin mapping.
2021-10-02 Got Port IO a little bit more right... Needs rework.
    [tttc.cpp]
2021-10-02 Base light PWM dimming demonstration.
2021-10-03 Proper port/pin mapping. Reduced timing from 82 to 62µs for screen refresh -> >8kHz update rate possible.
2021-10-03 Improvements in IO interface. Added ghosting prevention.
    [tttc.cpp]
2021-10-09 Smooth LED fading. More tick sound options.
2021-12-31 Use custom button class to reduce memory usage A LOT
2022-01-01 Some smaller optimizations on mem footprint + cleanup
2022-01-04 Add LED and tube brightness settings.
2022-01-16 Fixed SeparatorDot: Allow enabling/disabling in settings.
    [display.cpp, tttc.cpp]
2022-01-22 Add service menu to access reset and ACP functions.
    [tttc.cpp]
2022-01-22 Safe another 1128 bytes by using custom OPT3001 driver.
2022-01-22 Turn LED off in settings. Allow to escape from service state.
2022-01-23 Some cleanups. Reverted to tone() due to massive timing issues. Needs further investigation.
    [configuration.h]
2022-01-23 Fixed most of the brightness issues wrt. effects.
    [effects.cpp]
2022-01-23 Fixed previously introduced bug in ACP...
    [effects.cpp]
2022-01-24 Add transition and ambient effect settings.
    [configuration.h]
2022-01-24 Add NightTime mode. Finally using this ambient light sensor :-)
    [configuration.h]
2022-01-24 Feature complete! Add tube saving times modes.
    [configuration.h]
2022-03-25 Fixed errorneous transition when leaving option menu.
    [effects.cpp]
2022-03-26 Fixed sound issues by disabling display during playback. Reduce to 120 Hz update rate.
    [effects.cpp]
2022-03-27 Fixed short display glitch after sound playback
    [effects.cpp]
2022-03-27 Update Schematic and PCB to rev. 3
    [Drill_NPTH_Through.DRL, Drill_PTH_Through.DRL, Gerber_BoardOutline.GKO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]
2022-04-02 Reduce heat emission of LEDS by capping maximum brightness. Fixed dot-transition inconsistencies
    [effects.cpp]
2022-04-10 Add CAD files: Step (merged) and STLs.
    [button_single.stl, case.stl, spacer.stl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]
2023-02-11 Add Bill of Materials
